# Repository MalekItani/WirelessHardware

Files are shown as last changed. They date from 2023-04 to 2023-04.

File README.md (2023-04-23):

# Wireless Hardware
Welcome to the repository containing the circuit design files for wireless earbuds! In this repository, you will find all the necessary files to create your own wireless earbuds, including schematics, PCB layouts, and bill of materials.

## Software Dependencies/Requirements

- Kicad version 4.0 or greater.

## Repository Contents
This repository contains the following directories:

**Schematics**: Detailed diagrams of the circuitry used in the wireless earbuds.

**PCB layouts**: Physical layouts of the printed circuit board used in the wireless earbuds.

**Bill of materials**: A list of components and materials needed to build the wireless earbuds.

## Getting Started
To use these circuit design files, follow the steps below:

#### 1. Install KiCad: 
Download and install KiCad version 4.0 or greater from the official website. Choose the appropriate version for your operating system.

#### 2. Customize and Optimize: 
Import the schematics and PCB layouts into KiCad to begin customizing and optimizing the design to fit your specific needs. For detailed instructions on using KiCad, consult the official documentation.

## Firmware
The repository containing the firmware is located here: [https://github.com/antoniog11/OAEbud-firmware](https://github.com/antoniog11/OAEbud-firmware/)

## License
This repository is licensed under the MIT License. You are free to use and modify the circuit design files in any way you see fit, as long as you include the appropriate attribution and comply with the terms of the license.

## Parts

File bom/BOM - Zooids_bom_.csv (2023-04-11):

# | References | Value | Footprint | Datasheet | Description | Manufacturer | Manufacturer P/N | Vendor | Vendor P/N | Quantity
1 | C1, C2, C6, C9, C10, C11, C12, C14, C15, C16, C19 | 100nF | C_0402_1005Metric | https://media.digikey.com/pdf/Data%20Sheets/Samsung%20PDFs/CL05A104KA5NNNC.pdf | CAP CER 0.1UF 25V X5R 0402 | Samsung Electro-Mechanics | CL05A104KA5NNNC | Digi-key | 1276-1043-2-ND | 11
2 | C4, C5, C17 | 4.7uF | C_0603_1608Metric | https://media.digikey.com/pdf/Data%20Sheets/Samsung%20PDFs/CL10A475KP8NNNC_Spec.pdf | CAP CER 4.7UF 10V X5R 0603 | Samsung Electro-Mechanics | CL10A475KP8NNNC | Digi-key | 1276-1044-2-ND | 3
3 | C7, C13, C18 | 10uF | C_0603_1608Metric | https://www.samsungsem.com/kr/support/product-search/mlcc/CL10X106MO8NRNC.jsp | CAP CER 10UF 16V X6S 0603 | Samsung Electro-Mechanics | CL10X106MO8NRNC | Digi-key | 1276-6769-2-ND | 3
4 | C3 | 22nF | C_0402_1005Metric | https://media.digikey.com/pdf/Data%20Sheets/Samsung%20PDFs/CL05B223KP5NNNC_Spec.pdf | CAP CER 0.022UF 10V X7R 0402 | Samsung Electro-Mechanics | CL05B223KP5NNNC | Digi-key | 1276-1538-2-ND | 1
5 | C8 | 56nF | C_0402_1005Metric | https://www.yageo.com/upload/media/product/productsearch/datasheet/mlcc/UPY-GPHC_X7R_6.3V-to-50V_20.pdf | CAP CER 0.056UF 16V X7R 0402 | YAGEO | CC0402KRX7R7BB563 | Digi-key | 311-3805-2-ND | 1
6 | R5, R7, R14 | 10K | R_0402_1005Metric | https://fscdn.rohm.com/en/products/databook/datasheet/passive/resistor/chip_resistor/esr-e.pdf | RES SMD 10K OHM 5% 1/5W 0402 | Rohm Semiconductor | ESR01MZPJ103 | Digi-key | RHM1003TR-ND | 3
7 | R6, R11, R12 | dnp | R_0402_1005Metric |  | Do not place |  |  |  |  | 3
8 | R9, R10, R13 | 0R | R_0402_1005Metric | https://www.seielect.com/catalog/sei-rmcf_rmcp.pdf | RES 0 OHM JUMPER 1/16W 0402 | Stackpole Electronics Inc | RMCF0402ZT0R00 | Digi-key | RMCF0402ZT0R00TR-ND | 3
9 | R1, R3 | 50R | R_0402_1005Metric | https://www.yageo.com/upload/media/product/productsearch/datasheet/rchip/PYu-AC_51_RoHS_L_8.pdf | RES SMD 50 OHM 5% 1/16W 0402 | YAGEO | AC0402JR-0750RL | Digi-key | 13-AC0402JR-0750RLTR-ND | 2
10 | R2, R4 | 180R | R_0402_1005Metric | https://www.te.com/commerce/DocumentDelivery/DDEController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 | RES 180 OHM 1% 1/16W 0402 | TE Connectivity Passive Product | CRGCQ0402F180R | Digi-key | A129618TR-ND | 2
11 | R8 | 100K | R_0402_1005Metric | https://www.te.com/commerce/DocumentDelivery/DDEController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 | RES SMD 100K OHM 0.1% 1/16W 0402 | TE Connectivity Passive Product | CPF0402B100KE1 | Digi-key | A102574TR-ND | 1
12 | L1 | 2.2u | L_0805_2012Metric | https://search.murata.co.jp/Ceramy/image/img/P02/J(E)TE243A-0029_DFE201210U_reference.pdf | 2.2 µH Shielded Wirewound Inductor 1.2 A 228mOhm Max 0805 (2012 Metric) - | Murata Electronics | DFE201210U-2R2M=P2 | Digi-key | 490-16592-2-ND | 1
13 | D1 | LED | D_0603_1608Metric | https://media.digikey.com/pdf/Data%20Sheets/Harvatek%20PDFs/B18W1USD-20C000214U1930%20%20V1.2.pdf | LED SINGLE COLOR RED (1.6(L)X0.8 | Harvatek Corporation | B18W1USD-20C000214U1930 | Digi-key | 3147-B18W1USD-20C000214U1930TR-ND | 1
14 | U5, U6 | DRV8837CDSGR | SON50P200X200X80-9N | https://www.ti.com/general/docs/suppproductinfo.tsp?distId=10 | IC HALF-BRIDGE DRVR PWM 8WSON | Texas Instruments | DRV8837CDSGR | Digi-key | 296-47205-2-ND | 2
15 | U1 | B38G3RGB | B38G3RGB10D0003H2U1930 | https://media.digikey.com/pdf/Data%20Sheets/Harvatek%20PDFs/B38G3RGB-10D0003H2U1930%20%20V1.9.pdf | Red, Green, Blue (RGB) - LED Indication - Discrete 2V Red, 3V Green, 3V Blue 0606 (1616 Metric) | Harvatek Corporation | B38G3RGB-10D0003H2U1930 | Digi-key | 3147-B38G3RGB-10D0003H2U1930TR-ND | 1
16 | U2 | BUCK | LM3671TLX-3.3&slash_NOPB | https://www.ti.com/general/docs/suppproductinfo.tsp?distId=10 | Buck Switching Regulator IC Positive Fixed 3.3V 1 Output 600mA 5-WFBGA, DSBGA | Texas Instruments | LM3671TLX-3.3/NOPB | Digi-key | LM3671TLX-3.3/NOPBTR-ND | 1
17 | U3 | LTC4124 | LTC4124EV-TRMPBF | https://www.analog.com/media/en/technical-documentation/data-sheets/ltc4124.pdf | Wireless Charging ICs 100mA Wireless Li-Ion Charger | Analog Devices | LTC4124EV#TRMPBF | Mouser | 584-LTC4124EV#TRMPBF | 1
18 | U4 | MAX17048G+T10 | SON50P200X200X80-9N | https://datasheets.maximintegrated.com/en/ds/MAX17048-MAX17049.pdf | IC BATT MON LI-ION 1CELL 8TDFN | Analog Devices Inc./Maxim Integrated | MAX17048G+T10 | Digi-key | MAX17048G+T10TR-ND | 1
19 | U7 | MC3419 | LGA-12_2x2mm_P0.5mm | https://www.mouser.com/datasheet/2/821/MEMSIC_MC3419_Datasheet-1889799.pdf | Accelerometers Small Digital 3-axis Accelerometer Sensor | MEMSIC | MC3419 | Mouser | 498-MC3419 | 1
20 | U8 | ISP1807-LR-RS | ISP1807-LR-RS | https://www.insightsip.com/fichiers_insightsip/pdf/ble/ISP1807/isp_ble_DS1807.pdf | Bluetooth Bluetooth v5.0, Thread, Zigbee® Transceiver Module 2.402GHz ~ 2.48GHz Integrated, Trace Surface Mount | Insight SIP | ISP1807-LR-RS | Digi-key | 1786-1019-2-ND | 1
21 | U9 | MAX98357A | Maxim_WLP-9_1.595x1.415_Layout3x3_P0.4mm_Ball0.27mm_Pad0.25mm_NSMD | https://datasheets.maximintegrated.com/en/ds/MAX98357A-MAX98357B.pdf | IC AMP CLASS D MONO 3.2W 9WLP | Analog Devices Inc./Maxim Integrated | MAX98357AEWL+T | Digi-key | MAX98357AEWL+TTR-ND | 1
22 | MK1, MK2 | ICS-41352 | MIC_ICS-41350 | https://invensense.tdk.com/wp-content/uploads/2016/10/DS-000048-ICS-41352-data-sheet-v1.0.pdf | Bottom Port PDM Low Power muti-Mode Microphone with high AOP Mode | TDK-InvenSense | ICS-41352 | Digi-key | 1428-ICS-41352TR-ND | 2
23 | S1 | 450302014072 | 450302014072 | http://www.farnell.com/datasheets/1913864.pdf | Through Hole Slide Switch SPDT On-On 100 mA@ 42 V dc Slide | Wurth Elektronik | 450302014072 | Mouser | 710-450302014072 | 1
24 | SP1 | SPEAKER | Wire leads | http://puiaudio.com/pdf/AS01008MR-3-LW100-R.pdf | 8 Ohms General Purpose Speaker 500 mW 800 Hz ~ 20 kHz Top Round | PUI Audio, Inc. | AS01008MR-3-LW100-R | Digi-key | 668-AS01008MR-3-LW100-R-ND | 1
25 | J1 | 10118194-0001LF | AMPHENOL_10118194-0001LF | https://cdn.amphenol-icc.com/media/wysiwyg/files/documentation/datasheet/inputoutput/io_usb_micro.pdf | USB - micro B USB 2.0 Receptacle Connector 5 Position Surface Mount, Right Angle; Through Hole | Amphenol ICC (FCI) | 10118194-0001LF | Digi-key | 609-4618-2-ND | 1
26 | J2 | FTMH-106-03-L-DV | SAMTEC_FTMH-106-03-L-DV | https://www.mouser.com/datasheet/2/527/ftmh_sm-2854321.pdf | Board to Board & Mezzanine Connectors 1.00 mm Surface Mount Micro Terminal Strip | Samtec | FTMH-106-03-L-DV | Mouser | 200-FTMH10603LDV | 1
27 | P1 | BATT_TERM | JST_ACH_BM02B-ACHSS-GAN-ETF_1x02-1MP_P1.20mm_Vertical | https://www.jst-mfg.com/product/pdf/eng/eACH.pdf | Connector Header Surface Mount, Right Angle 2 position 0.047" (1.20mm) | JST Sales America Inc. | BM02B-ACHSS-GAN-ETF(LF)(SN | Digi-key | 455-3277-2-ND | 1
28 | P3 | M2_TERM | PinHeader_1x02_P1.27mm_Vertical |  | Do not place |  |  |  |  | 1
29 | P4 | M1_TERM | PinHeader_1x02_P1.27mm_Vertical |  | Do not place |  |  |  |  | 1

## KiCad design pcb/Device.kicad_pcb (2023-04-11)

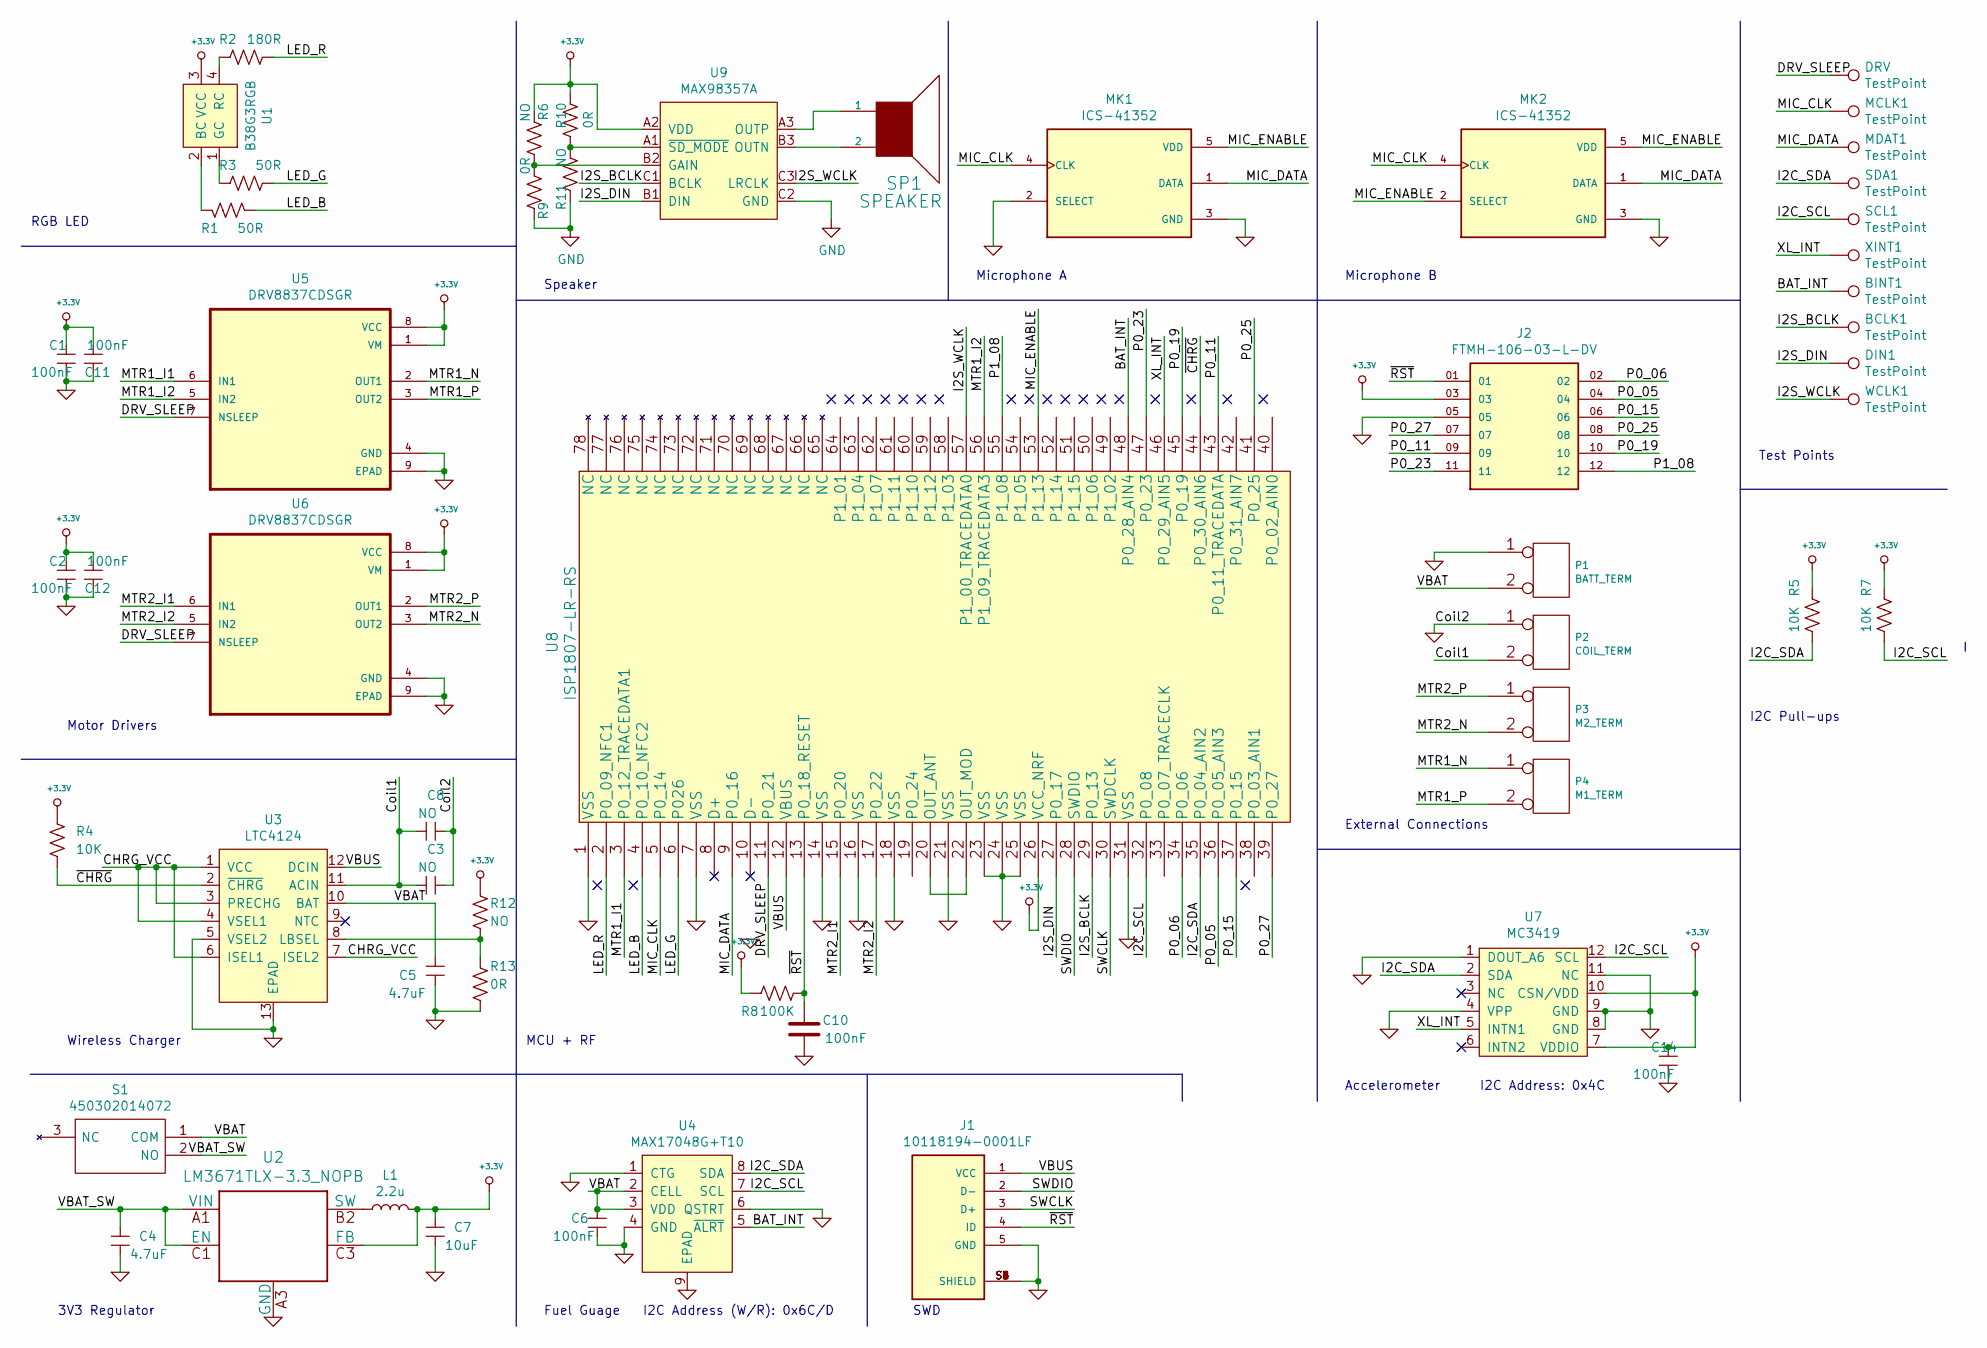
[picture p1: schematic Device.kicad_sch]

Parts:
BCLK1: TestPoint; TestPoint_Pad_D1.0mm
BINT1: TestPoint; TestPoint_Pad_D1.0mm
C1, C2, C6, C10, C11, C12, C14: 100nF; C_0402_1005Metric
C3, C8: NO; C_0402_1005Metric
C4, C5: 4.7uF; C_0603_1608Metric
C7: 10uF; C_0603_1608Metric
DIN1: TestPoint; TestPoint_Pad_D1.0mm
DRV: TestPoint; TestPoint_Pad_D1.0mm
J1: 10118194-0001LF; AMPHENOL_10118194-0001LF; PARTREV B
J2: FTMH-106-03-L-DV; SAMTEC_FTMH-106-03-L-DV; Manufacturer P/N FTMH-106-03-L-DV
L1: 2.2u; L_0805_2012Metric; Manufacturer P/N DFE201210U-2R2M=P2
MCLK1: TestPoint; TestPoint_Pad_D1.0mm
MDAT1: TestPoint; TestPoint_Pad_D1.0mm
MK1, MK2: ICS-41352; MIC_ICS-41350; Manufacturer P/N ICS-41352
P1: BATT_TERM; JST_ACH_BM02B-ACHSS-GAN-ETF_1x02-1MP_P1.20mm_Vertical; Manufacturer P/N BM02B-ACHSS-GAN-ETF(LF)(SN
P2: COIL_TERM; TestPoint_2Pads_Pitch2.54mm_Drill0.8mm
P3: M2_TERM; PinHeader_1x02_P1.27mm_Vertical
P4: M1_TERM; PinHeader_1x02_P1.27mm_Vertical
R1, R3: 50R; R_0402_1005Metric
R2: 180R; R_0402_1005Metric
R4, R5, R7: 10K; R_0402_1005Metric
R6, R11, R12: NO; R_0402_1005Metric
R8: 100K; R_0402_1005Metric
R9, R10, R13: 0R; R_0402_1005Metric
S1: 450302014072; Manufacturer P/N 450302014072
SCL1: TestPoint; TestPoint_Pad_D1.0mm
SDA1: TestPoint; TestPoint_Pad_D1.0mm
SP1: SPEAKER; CUI_CMT-4023S-SMT-TR; Manufacturer P/N SMT-0440-T-HT-R
U1: B38G3RGB; B38G3RGB10D0003H2U1930; Manufacturer P/N B38G3RGB-10D0003H2U1930
U2: LM3671TLX-3.3_NOPB; LM3671TLX-3.3&slash_NOPB; Manufacturer P/N LM3671TLX-3.3/NOPB
U3: LTC4124; LTC4124EV-TRMPBF; Manufacturer P/N LTC4124EV#TRMPBF
U4: MAX17048G+T10; SON50P200X200X80-9N; Manufacturer P/N MAX17048G+T10
U5, U6: DRV8837CDSGR; SON50P200X200X80-9N; Manufacturer P/N DRV8837CDSGR
U7: MC3419; LGA-12_2x2mm_P0.5mm; Manufacturer P/N MC3419
U8: ISP1807-LR-RS; Manufacturer P/N ISP1807-LR-RS
U9: MAX98357A; Maxim_WLP-9_1.595x1.415_Layout3x3_P0.4mm_Ball0.27mm_Pad0.25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; Manufacturer P/N MAX98357AEWL+T
WCLK1: TestPoint; TestPoint_Pad_D1.0mm
XINT1: TestPoint; TestPoint_Pad_D1.0mm

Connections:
+3.3V: C1.1, C2.1, C7.2, C11.2, C12.2, C14.1, J2.03, L1.2, R4.1, R5.1, R6.2, R7.1, R8.1, R10.1, R12.1, U1.3 (VCC), U2.C3 (FB), U5.1 (VM), U5.8 (VCC), U6.1 (VM), U6.8 (VCC), U7.7 (VDDIO), U7.10 (CSN/VDD), U8.26 (VCC_NRF), U9.A2 (VDD)
/BAT_INT: BINT1.1, U4.5 (~ALRT), U8.48 (P0_28_AIN4)
/CHRG_VCC: U3.1 (VCC), U3.3 (PRECHG), U3.4 (VSEL1), U3.6 (ISEL1), U3.7 (ISEL2)
/Coil1: C3.2, C8.2, P2.2 (PM), U3.11 (ACIN)
/DRV_SLEEP: DRV.1, U5.7 (NSLEEP), U6.7 (NSLEEP), U8.11 (P0_21); also elsewhere on the board
/I2C_SCL: R7.2, SCL1.1, U4.7 (SCL), U7.12 (SCL), U8.32 (P0_08)
/I2C_SDA: R5.2, SDA1.1, U4.8 (SDA), U7.2 (SDA), U8.35 (P0_04_AIN2)
/I2S_BCLK: BCLK1.1, U8.29 (P0_13), U9.C1 (BCLK)
/I2S_DIN: DIN1.1, U8.27 (P0_17), U9.B1 (DIN)
/I2S_WCLK: U8.57 (P1_00_TRACEDATA0), U9.C3 (LRCLK), WCLK1.1
/LED_B: R1.2, U8.4 (P0_10_NFC2)
/LED_G: R3.2, U8.6 (P026)
/LED_R: R2.2, U8.2 (P0_09_NFC1)
/MIC_CLK: MCLK1.1, MK1.4 (CLK), MK2.4 (CLK), U8.5 (P0_14)
/MIC_DATA: MDAT1.1, MK1.1 (DATA), MK2.1 (DATA), U8.9 (P0_16)
/MIC_ENABLE: MK1.5 (VDD), MK2.2 (SELECT), MK2.5 (VDD), U8.53 (P1_13)
/MTR1_I1: U5.6 (IN1), U8.3 (P0_12_TRACEDATA1)
/MTR1_I2: U5.5 (IN2), U8.56 (P1_09_TRACEDATA3)
/MTR1_N: P4.1, U5.2 (OUT1)
/MTR1_P: P4.2 (PM), U5.3 (OUT2)
/MTR2_I1: U6.6 (IN1), U8.15 (P0_20)
/MTR2_I2: U6.5 (IN2), U8.17 (P0_22)
/MTR2_N: P3.2 (PM), U6.3 (OUT2)
/MTR2_P: P3.1, U6.2 (OUT1)
/P0_05: J2.04, U8.36 (P0_05_AIN3)
/P0_06: J2.02, U8.34 (P0_06)
/P0_11: J2.09, U8.43 (P0_11_TRACEDATA)
/P0_15: J2.06, U8.37 (P0_15)
/P0_19: J2.10, U8.45 (P0_19)
/P0_23: J2.11, U8.47 (P0_23)
/P0_25: J2.08, U8.41 (P0_25)
/P0_27: J2.07, U8.39 (P0_27)
/P1_08: J2.12, U8.55 (P1_08)
/SWCLK: J1.3 (D+), U8.30 (SWDCLK)
/SWDIO: J1.2 (D-), U8.28 (SWDIO)
/VBAT: C5.1, C6.2, P1.2 (PM), S1.1 (COM), U3.10 (BAT), U4.2 (CELL), U4.3 (VDD)
/VBAT_SW: C4.2, S1.2 (NO), U2.A1 (VIN), U2.C1 (EN)
/VBUS: J1.1 (VCC), U3.12 (DCIN), U8.12 (VBUS)
/XL_INT: U7.5 (INTN1), U8.46 (P0_29_AIN5), XINT1.1
/~CHRG: R4.2, U3.2 (~CHRG), U8.44 (P0_30_AIN6)
/~RST: C10.1, J1.4 (ID), J2.01, R8.2, U8.13 (P0_18_RESET)
GND: C1.2, C2.2, C3.1, C4.1, C5.2, C6.1, C7.1, C8.1, C10.2, C11.1, C12.1, C14.2, J1.5 (GND), J1.S1 (SHIELD), J1.S2 (SHIELD), J1.S3 (SHIELD), J1.S4 (SHIELD), J1.S5 (SHIELD), J1.S6 (SHIELD), J2.05, MK1.2 (SELECT), MK1.3 (GND), MK2.3 (GND), P1.1, P2.1, R9.1, R11.1, R13.2, U2.A3 (GND), U3.5 (VSEL2), U3.13 (EPAD), U4.1 (CTG), U4.4 (GND), U4.6 (QSTRT), U4.9 (EPAD), U5.4 (GND), U5.9 (EPAD), U6.4 (GND), U6.9 (EPAD), U7.1 (DOUT_A6), U7.4 (VPP), U7.8 (GND), U7.9 (GND), U7.11 (NC), U8.1 (VSS), U8.7 (VSS), U8.14 (VSS), U8.16 (VSS), U8.18 (VSS), U8.21 (VSS), U8.23 (VSS), U8.24 (VSS), U8.25 (VSS), U8.31 (VSS), U9.C2 (GND)
unnamed: L1.1, U2.B2 (SW)
unnamed: R1.1, U1.2 (BC)
unnamed: R2.1, U1.4 (RC)
unnamed: R3.1, U1.1 (GC)
unnamed: R6.1, R9.2, U9.B2 (GAIN)
unnamed: R10.2, R11.2, U9.A1 (~SD_MODE)
unnamed: R12.2, R13.1, U3.8 (LBSEL)
unnamed: SP1.1, U9.A3 (OUTP)
unnamed: SP1.2, U9.B3 (OUTN)
unnamed: U8.20 (OUT_ANT), U8.22 (OUT_MOD)

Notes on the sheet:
3V3 Regulator
I2C Pull-ups
Test Points
Wireless Charger
SWD
MCU + RF
RGB LED
Motor Drivers
Speaker
Fuel Guage
Microphone B
External Connections
Accelerometer
Microphone A
I2C Address: 0x4C
I2C Address (W/R): 0x6C/D

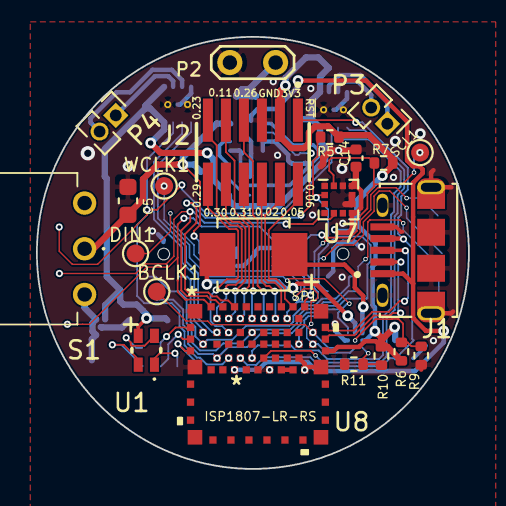
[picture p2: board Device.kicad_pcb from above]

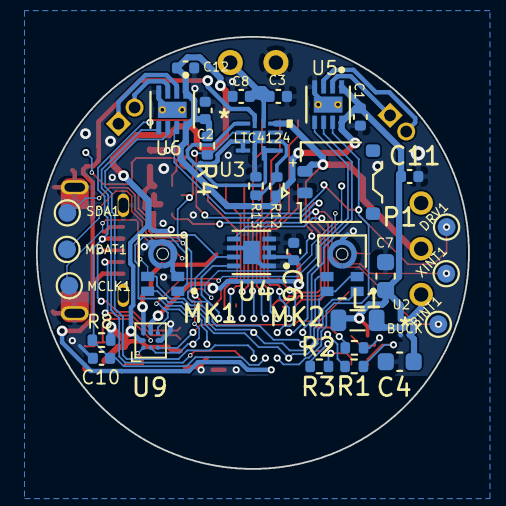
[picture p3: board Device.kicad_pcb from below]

Board: 2 copper layers, 24.0 x 24.0 mm, 55 parts (33 on the bottom side), 52 nets.

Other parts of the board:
DRV1: TestPoint; TestPoint_Pad_D1.0mm

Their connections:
/DRV_SLEEP: DRV1.1; also elsewhere on the board

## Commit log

2023-04-11 Added BOM
    [BOM - Zooids_bom_.csv]
2023-04-11 Updated speaker
    [BOM - Zooids_bom_.csv]

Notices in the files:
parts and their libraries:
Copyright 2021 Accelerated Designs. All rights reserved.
